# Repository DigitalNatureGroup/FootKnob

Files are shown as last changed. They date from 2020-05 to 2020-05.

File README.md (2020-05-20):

# 3D Printable Attachment for Opening a Door without Hand

## About / 概要

There is always a door at the partition of the room, and we touch the doorknob multiple times a day.
Recently, COVID-19 has become widespread, and we have to work to prevent infection.
Considering that unspecified number of people are touching the doorknob every day, another way of opening the door is needed.
So I devised a way to open the door without touching the doorknob.
Consisting of parts that can be printed with a personal 3D printer and screws / bolts available at home centers,
It can be attached to a lever type door knob. (Google Translated)

部屋の区切りには必ずドアは存在し、私達は1日に複数回にわたってドアノブを触ります。
2020年5月現在、新型コロナウイルスの流行により、手指衛生を伴う感染予防は私たちの生活に必要不可欠になりました。
手指衛生の観点からドアノブに手で触れずに日常生活を行うために、ドアをドアノブにふれることなく開ける方法を考案しました。パーソナルな3Dプリンタで印刷できる部品とホームセンターで手に入るネジ/ボルトで構成され、レバータイプのドアノブに取り付けが可能です。



## Parts List / 部品リスト

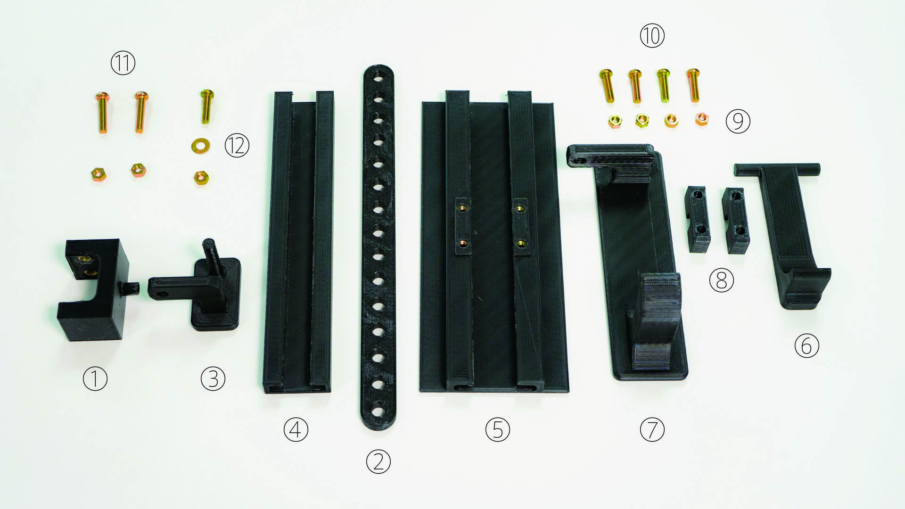
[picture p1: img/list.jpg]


|Number/番号|Component Name/パーツ名|Quantity/個数|Printable STL data/STLデータ| CAD Data (.step)/CADデータ|Other/備考|
|:-:|:-:|-|-|-|-|
|1|Knob Attachment/ノブアタッチメント| 1 | [Download](https://github.com/DigitalNatureGroup/FootKnob/raw/master/stl/attachment.stl) | [Download](https://github.com/DigitalNatureGroup/FootKnob/raw/master/step/attachment.step) | |
|2|Link/リンク| 1 | [Download](https://github.com/DigitalNatureGroup/FootKnob/raw/master/stl/link.stl) | [Download](https://github.com/DigitalNatureGroup/FootKnob/raw/master/step/link.step) | |
|3|Slider/スライダ| 1 | [Download](https://github.com/DigitalNatureGroup/FootKnob/raw/master/stl/slider_left.stl) | [Download](https://github.com/DigitalNatureGroup/FootKnob/raw/master/step/slider.step) |Knob on the left/ドアノブが左の場合|
|-|Slider/スライダ| 1 | [Download](https://github.com/DigitalNatureGroup/FootKnob/raw/master/stl/slider_right.stl) | [Download](https://github.com/DigitalNatureGroup/FootKnob/raw/master/step/slider.step) |Knob on the right/ドアノブが右の場合|
|4|Guide Rail(Upper)/ガイドレール(上)| 1 | [Download](https://github.com/DigitalNatureGroup/FootKnob/raw/master/stl/guiderail_upper.stl) | [Download](https://github.com/DigitalNatureGroup/FootKnob/raw/master/step/guiderail_upper.step) | |
|5|Guide Rail(Lower)/ガイドレール(下)| 1 | [Download](https://github.com/DigitalNatureGroup/FootKnob/raw/master/stl/guiderail_lower.stl) | [Download](https://github.com/DigitalNatureGroup/FootKnob/raw/master/step/guiderail_lower.step) | |
|6|Pedal/ペダル| 1 | [Download](https://github.com/DigitalNatureGroup/FootKnob/raw/master/stl/pedal.stl) | [Download](https://github.com/DigitalNatureGroup/FootKnob/raw/master/step/pedal.step) | |
|7|Pedal Slider/ペダルスライダ| 1 | [Download](https://github.com/DigitalNatureGroup/FootKnob/raw/master/stl/pedalslider_left.stl) | [Download](https://github.com/DigitalNatureGroup/FootKnob/raw/master/step/pedalslider.step) |Knob on the left/ドアノブが左の場合|
|-|Pedal Slider/ペダルスライダ| 1 | [Download](https://github.com/DigitalNatureGroup/FootKnob/raw/master/stl/pedalslider_right.stl) | [Download](https://github.com/DigitalNatureGroup/FootKnob/raw/master/step/pedalslider.step) |Knob on the right/ドアノブが右の場合|
|8|Cap/キャップ| 2 | [Download](https://github.com/DigitalNatureGroup/FootKnob/raw/master/stl/cap.stl) | [Download](https://github.com/DigitalNatureGroup/FootKnob/raw/master/step/cap.step) | |
|9|M5 Hexagon nut/M5 六角ナット| 7 | - | - | |
|10|M5x20mm Screw/M5x20mm ネジ| 5 | - | - | |
|11|M5x25mm Screw/M5x25mm ネジ| 2 | - | - | |
|12|M5 Washer/M5 ワッシャー| 1 | - | - | |
|(13)|M6 Flush Cut Bolt/M6全ねじ| 1 | - | - |【Optional】Linker of Each Slider/【オプション】スライダ同士を繋ぐ用|
|(14)|M6 Hexagon nut/M6 六角ナット| 4 | - | - |【Optional】Linker of Each Slider/【オプション】スライダ同士を繋ぐ用|

## How to Build / 組み立て方

1. Assemble the attachment part to the door knob / ドアノブへのアタッチメント部分を組み立て
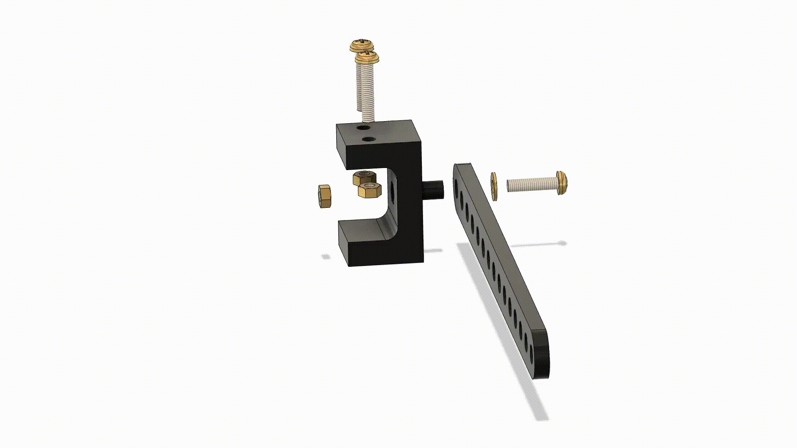
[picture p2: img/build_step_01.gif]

1. Attach the attachment part to the door knob / アタッチメント部分をドアノブに取り付け
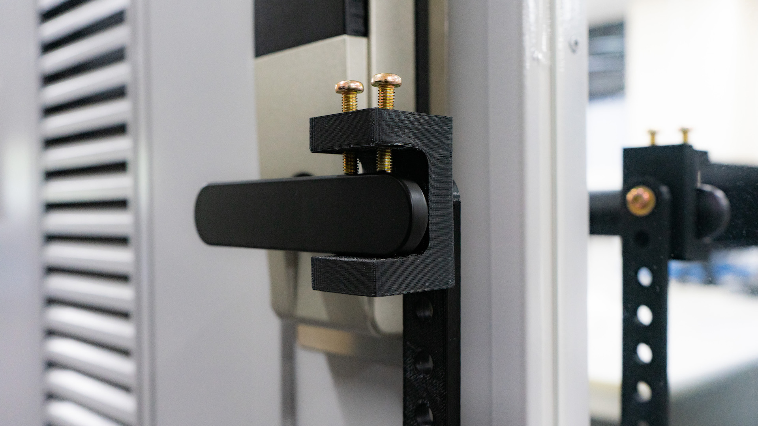
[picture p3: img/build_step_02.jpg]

1. Attach the slider and guide to the door and connect the links / スライダ,ガイドをドアに取り付けてリンクを繋ぐ
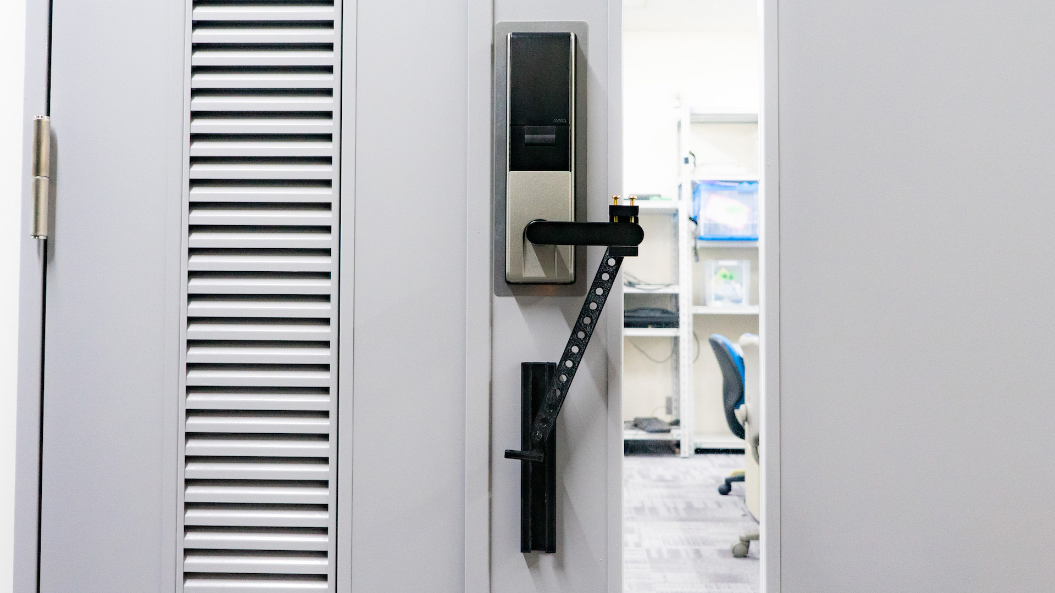
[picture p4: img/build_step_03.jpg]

1. Assemble the pedal part / ペダル部分を組み立て
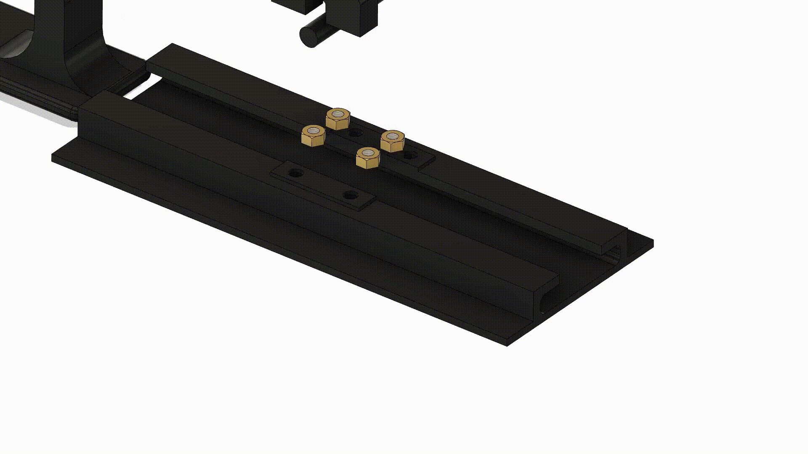
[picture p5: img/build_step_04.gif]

1. Attach the pedal part to the door / ペダル部分をドアの取り付け
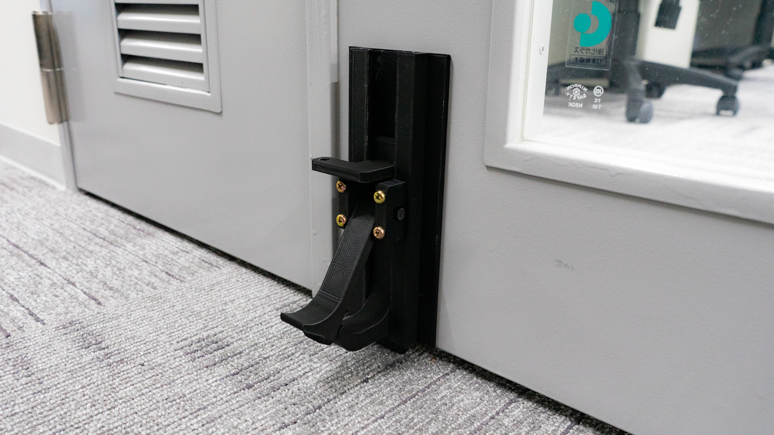
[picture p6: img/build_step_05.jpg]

1. Connect each slider / スライダ同士を繋ぐ
1. Finish / 完成
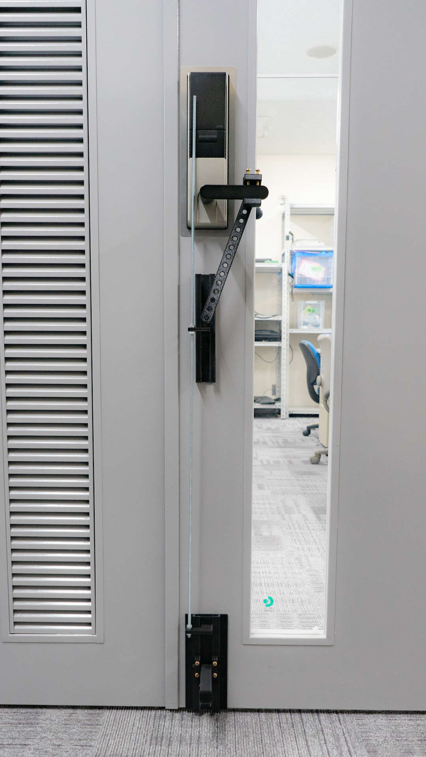
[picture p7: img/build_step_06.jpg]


## Citation / 引用
```
@misc{FootKnob2020,
    author  = {Tatsuya Minagawa},
    title   = {3D Printable Attachment for Opening a Door without Hand},
    note    = {\url{https://github.com/DigitalNatureGroup/FootKnob}},
    year    = {2020}
    month   = {may}
}
```

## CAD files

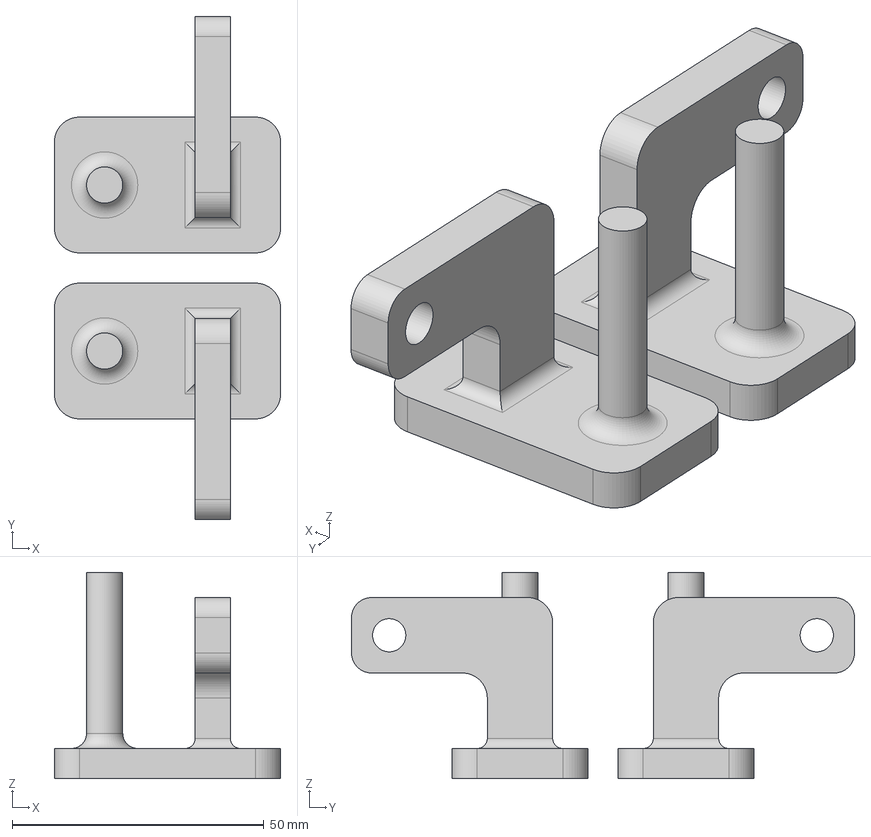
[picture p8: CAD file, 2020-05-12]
step/slider.step
45.0 x 100.0 x 41.0 mm

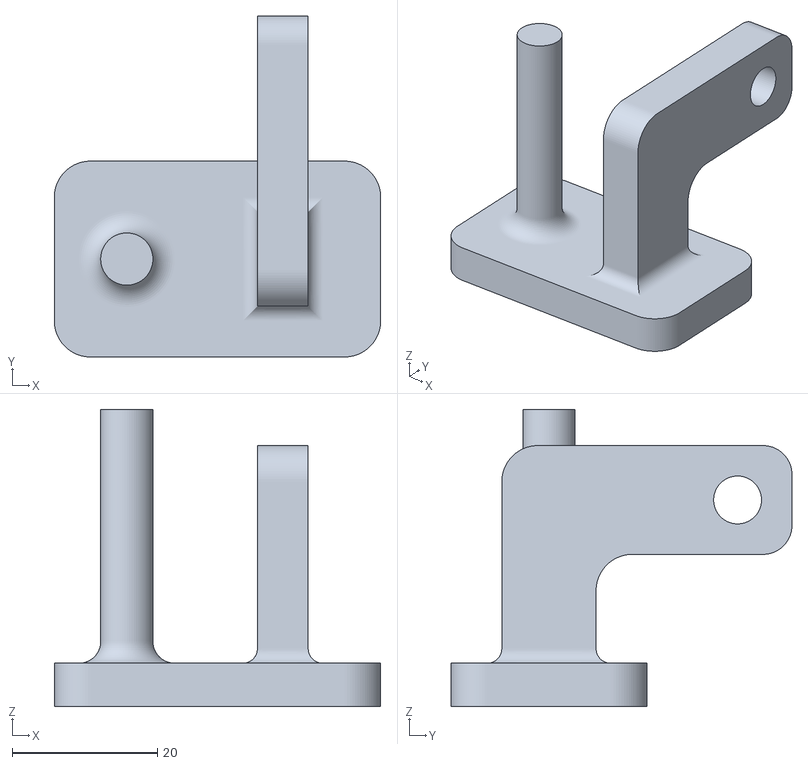
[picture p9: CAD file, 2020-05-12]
stl/slider_right.stl
45.0 x 47.0 x 41.0

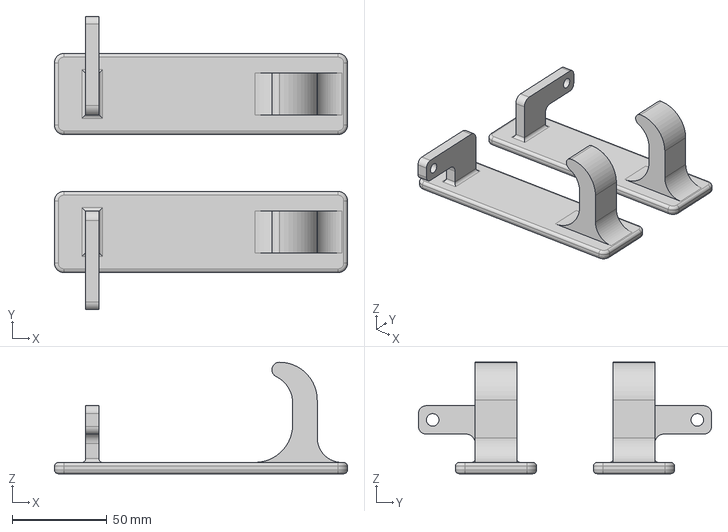
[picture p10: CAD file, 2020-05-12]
step/pedalslider.step
155.0 x 155.0 x 59.0 mm

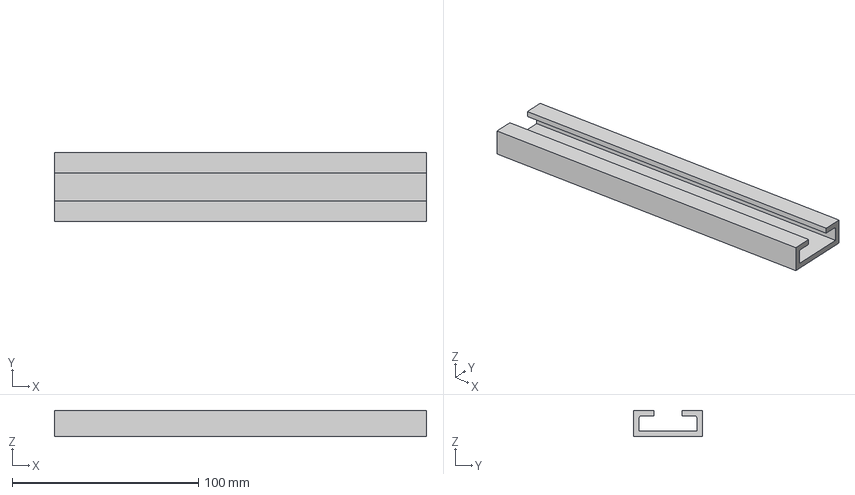
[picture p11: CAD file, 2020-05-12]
step/guiderail_upper.step
200.0 x 37.0 x 14.0 mm

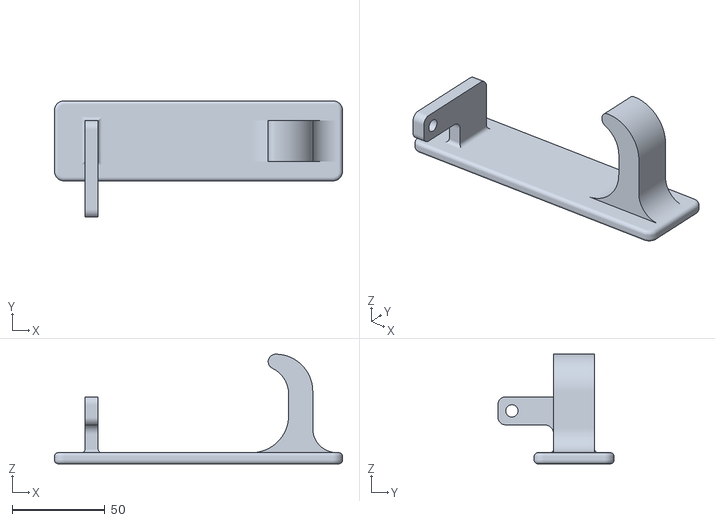
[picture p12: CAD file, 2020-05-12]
stl/pedalslider_left.stl
155.0 x 62.5 x 59.0

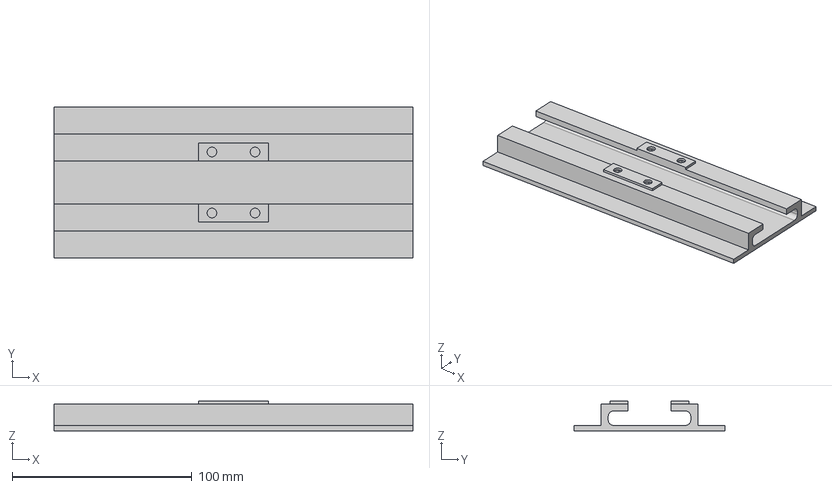
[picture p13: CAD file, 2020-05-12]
step/guiderail_lower.step
200.0 x 84.0 x 16.5 mm

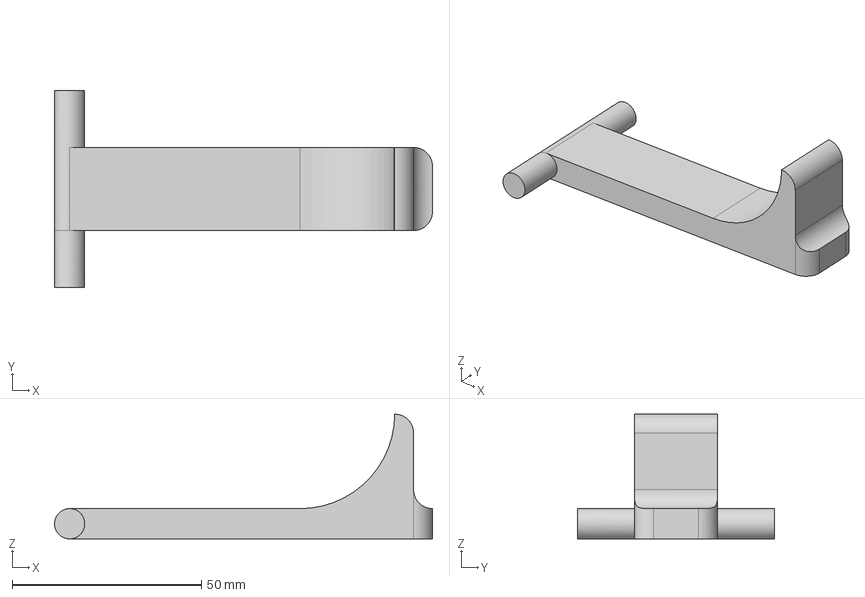
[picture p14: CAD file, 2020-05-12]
step/pedal.step
100.0 x 52.0 x 33.0 mm

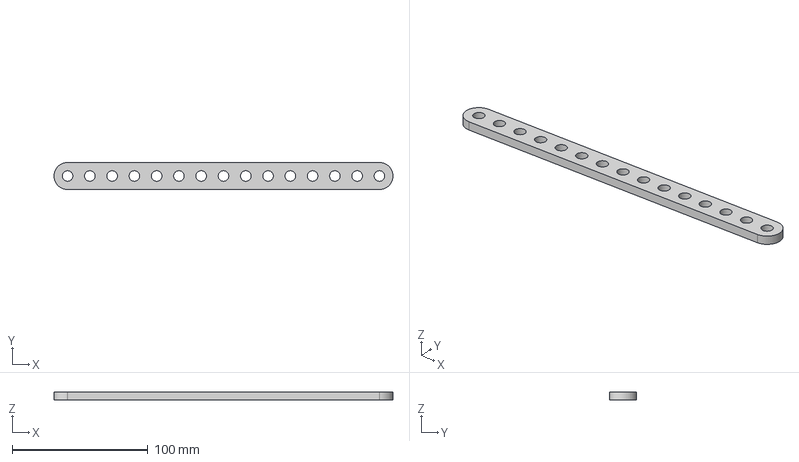
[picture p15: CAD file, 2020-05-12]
step/link.step
250.0 x 20.0 x 6.00 mm

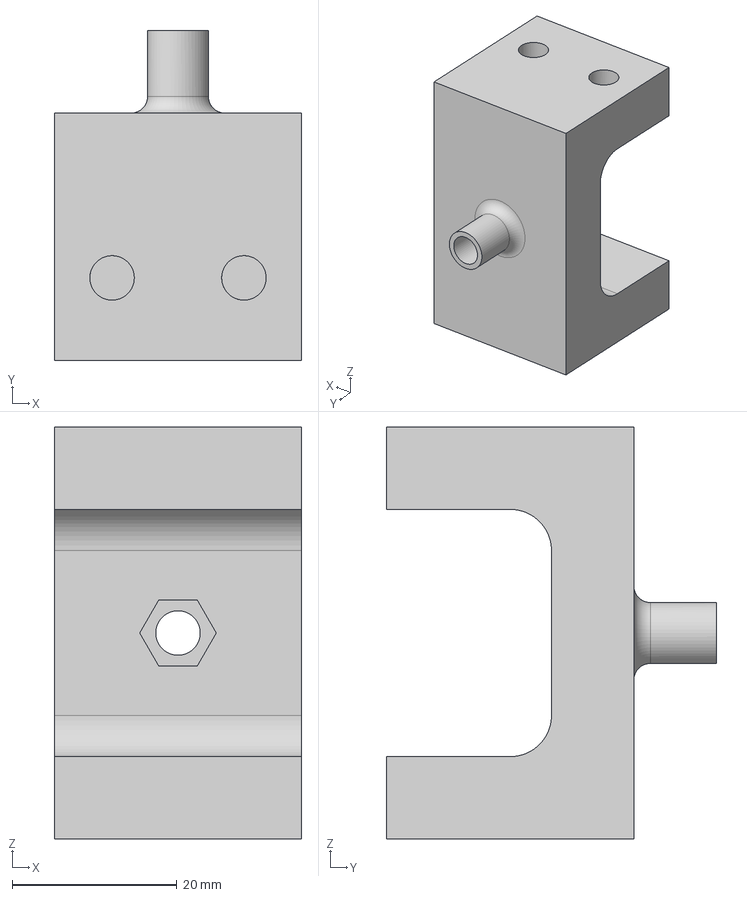
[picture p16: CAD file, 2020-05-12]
step/attachment.step
30.0 x 40.0 x 50.0 mm

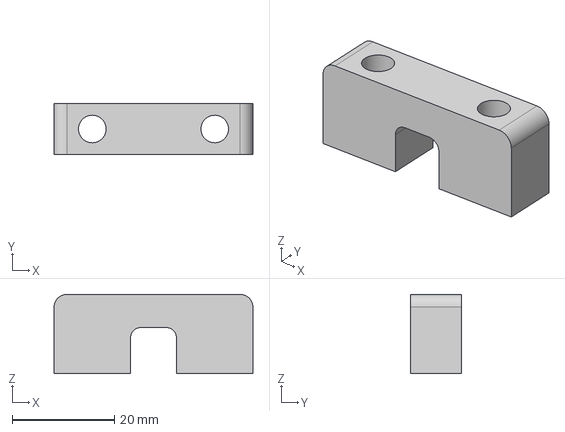
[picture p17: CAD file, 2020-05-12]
step/cap.step
39.0 x 10.0 x 15.5 mm

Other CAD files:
stl/slider_left.stl
stl/pedalslider_right.stl
stl/attachment.stl
stl/cap.stl
stl/guiderail_lower.stl
stl/guiderail_upper.stl
stl/link.stl
stl/pedal.stl

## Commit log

2020-05-10 gitignoreを追加
2020-05-10 画像を追加
2020-05-10 descriptionを追加
2020-05-12 部品リストを作成
2020-05-12 左右を追加
2020-05-12 キャップのstlデータを追加
    [cap.stl]
2020-05-12 キャップのCADデータを追加
    [cap.step]
2020-05-12 attachmentのデータを追加
    [attachment.step, attachment.stl]
2020-05-12 リンクのデータを追加
    [link.step, link.stl]
2020-05-12 pedalのデータを追加
    [pedal.step, pedal.stl]
2020-05-12 ガイドのデータを追加
    [guiderail_lower.step, guiderail_lower.stl, guiderail_upper.step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]
2020-05-12 pedalSliderのデータを追加
    [pedalslider.step, pedalslider_left.stl, pedalslider_right.stl]
2020-05-12 スライダのデータを追加
    [slider.step, slider_left.stl, slider_right.stl]
2020-05-12 部品リストの画像を追加
2020-05-12 少し文章を修正
2020-05-12 1番目の手順の画像と、その他手順のテキストを追加
2020-05-12 アタッチメントの取り付け部分の画像を追加
2020-05-13 pedal部分の画像を追加
2020-05-13 残りの組み立て方の画像を追加
2020-05-13 publish用の設定に変更
2020-05-13 日本語を修正
2020-05-20 miscを追加
2020-05-20 タイトルと見出しを修正
2020-05-28 LICENCEを追加
